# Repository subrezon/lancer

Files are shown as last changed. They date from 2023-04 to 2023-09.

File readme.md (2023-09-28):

# Lancer

The Lancer is a 36-key ortholinear keyboard with a light split and a focus on compact footprint and portability. It is a direct successor to [la_nc](https://github.com/subrezon/la_nc), and is very much inspired by other keyboards like Planck, Lumberjack and Lesovoz.





# Features

- Width of just 11U, the smallest possible with 10 columns and a top-mounted Pro Micro
- More focused thumb row, featuring 6 easily accessible keys
- Powered by a Pro Micro or any other compatible MCU board
- Hotswap sockets in south-facing orientation
- Integrated battery support with a power switch
- Native 3-wire SPI for nice!view support without any bodge wires
- Backwards compatible with oldschool SSD1306 OLEDs (4 leftmost pins of the SPI header)  

# BOM

| Item | Count | Notes |
| :- | :- | :- |
| PCB | 1x | [Gerber file](https://github.com/subrezon/lancer/raw/master/gerbers/lancer-pcb-hotswap/lancer-hotswap-pcb.zip) |
| Top plate | 1x | [Gerber for FR4](https://github.com/subrezon/lancer/raw/master/gerbers/lancer-top-plate/lancer-top-plate.zip), [dxf for other materials](https://github.com/subrezon/lancer/raw/master/dxf/top-plate.dxf) |
| Bottom plate | 1x | [Gerber for FR4](https://github.com/subrezon/lancer/raw/master/gerbers/lancer-bottom-plate/lancer-bottom-plate.zip), [dxf for other materials](https://github.com/subrezon/lancer/raw/master/dxf/bottom-plate.dxf) |
| Pro Micro | 1x | other boards with compatible pinout also work |
| SMD Diodes | 36x | 1N4148W SOD123 |
| MX Hotswap sockets | 36x | Kailh or Gateron |
| Tactile button | 1x | 3x6mm 2-pin button |
| M2 screws | 16x | M2x4 or M2x5, head diameter <5mm |
| M2 standoffs | 8x | 8mm recommended[^1] |
| MX-style switches| 36x | 3-pin or 5-pin |
| 1U MX keycaps | 36x |  |

For wireless operation:

| Item | Count | Notes |
| :- | :- | :- |
| Wireless Pro Micro | 1x | nice!nano, nrfmicro, etc. |
| Rechargeable battery | 1x | 3.7V two-wire battery (eg. 350926) |
| 7-pin SPDT switch | 1x | MSK-12C02 or compatible |

Optionally:

| Item | Count | Notes |
| :- | :- | :- |
| Pro Micro socket | 1-2x | either 1x 24-pin wide or 2x 12-pin single-row |
| Screen | 1x | either nice!view or SSD1306 128x32 OLED |
| Screen socket | 1x | 5-pin |
| Screen cover | 1x | dxf file (coming soon) |

[^1]: 8mm is recommended and will result in equal spacing between top plate, PCB and bottom plate. 7mm can be used for the lowest possible profile, however it is only compatible with Kailh sockets - Gateron sockets slightly thicker.

# Tools

Required:

- Soldering iron/station (+ solder, flux, etc.)
- Screwdriver for the screws
- Side cutters (regular wire cutters will do in a pinch)

Optional (but very recommended):

- Tweezers (preferably reverse ones, for placing diodes & sockets)
- Breadboard (for aligning ProMicro pins)
- Tape (for holding components in place)

Safety measures:

- Fan (for blowing solder fumes away from your face)
- Eye protection (for trimming pins)

# PCB & plates fabrication

Upload the [PCB gerber file](https://github.com/subrezon/lancer/raw/master/gerbers/lancer-pcb-hotswap/lancer-hotswap-pcb.zip) to a PCB manufacturer site like JLCPCB or PCBWay. You can keep settings at default and just pick the color.

If you want FR4 plates, upload [top plate](https://github.com/subrezon/lancer/raw/master/gerbers/lancer-top-plate/lancer-top-plate.zip) and [bottom plate](https://github.com/subrezon/lancer/raw/master/gerbers/lancer-bottom-plate/lancer-bottom-plate.zip) gerbers in the same fashion. If you want plastic or metal plates, use [top plate](https://github.com/subrezon/lancer/raw/master/dxf/top-plate.dxf) and [bottom plate](https://github.com/subrezon/lancer/raw/master/dxf/bottom-plate.dxf) dxf files for cutting.

# Build guide

[Here is a WIP build guide in english](https://github.com/subrezon/lancer/blob/master/docs/build-guide.md). Feel free to submit better photos or translations!

# Firmware

Lancer supports all 3 major firmwares: QMK, ZMK and KMK.

Lancer support in QMK and KMK has been merged into their respective official repositories.

ZMK is user config repository only. Merging into official ZMK repository is currently not planned.

## QMK

The keyboard ID is `subrezon/lancer` in QMK.

Here is an example of flashing the keyboard with the default firmware using the QMK CLI:

```
qmk flash -kb subrezon/lancer -km default
```

If you're unsure what to do with this information, check out the [QMK Documentation](https://docs.qmk.fm/#/) for information on how to get started with QMK.

- I currently do not offer VIA support.
- QMK currently does not support nice!view E-Ink screens.
- If you want to use an SSD1306 OLED, [read this](https://docs.qmk.fm/#/feature_oled_driver) to make it work. The default firmware does not feature any screen support.
- The default firmware is set up for oldschool atmega32u4-based Pro Micros with the caterina bootloader. If you're using an STM or RP2040-based board, you will need to set CONVERT_TO accordingly in your keymap's rules.mk file. [Read this](https://docs.qmk.fm/#/feature_converters?id=converters) for further information.

## ZMK

You can use [this ZMK user config repository](https://github.com/subrezon/zmk-config-lancer) to build ZMK firmware for Lancer. You can:

- Download pre-built firmware from that repository. It is configured for nice!nano v2 and uses the default keymap.
- If you wish to change the keymap and/or use an MCU board other than nice!nano v2, fork that repository and edit the files to suit your needs. The keymap is under `config/boards/shields/lancer/lancer.keymap`.
- If you already have a ZMK user config repository, you may integrate the contents of that repository into your own. Copy the `config/boards/shields/lancer` directory into your repository, then edit your build.yaml to include Lancer:

```
---
include:
  - board: your_other_board
    shield: your_other_shield
  - board: nice_nano_v2
    shield: lancer
```

If you are using an MCU board other than nice!nano v2, change the `nice_nano_v2` board identifier to whatever your board's identifier is. You can find supported boards and their respective identifiers [here](https://zmk.dev/docs/hardware#pro_micro).

If you're new to ZMK, check out the [ZMK documentation](https://zmk.dev/docs) on how to get started.

Note: I might get around to get Lancer officially supported in ZMK main repo, but I feel like Lancer would need to become at least moderately popular first to justify the work. A public user config repo will do for now.

## KMK

To install KMK firmware on your Lancer, follow these steps:

- Download the latest release of [CircuitPython](https://circuitpython.org/downloads) for your MCU board.
- Connect your MCU board to the computer and put it into flashing mode, usually by double-tapping RESET (non-RP2040), or holding BOOT and pressing RESET (RP2040)
- A USB storage device will appear. Copy the `adafruit-circuitpython-*.uf2` you just downloaded onto it and wait. The board will reboot and appear again as a USB storage device named `CIRCUITPY`.
- Download or clone the [KMK Firmware Repository](https://github.com/KMKfw/kmk_firmware). Copy the `kmk` folder and the `boot.py` file onto the MCU.
  - If you use a nice!nano or another MCU board with only 1MB of flash, you will need to [compile the firmware](http://kmkfw.io/docs/Officially_Supported_Microcontrollers#pre-compiling-kmk-for-nicenano) first.
- Delete the `code.py` file, and copy `main.py` and `kb.py` from the `boards/subrezon/lancer` folder.

The `kb.py` file has been set up for nice!nano v2. If you have another MCU board - open the `kb.py` folder and look at line 5. It says:

```
from kmk.quickpin.pro_micro.nice_nano import pinout as pins
```

Change `nice_nano` to match your MCU board. [These ones are supported](https://github.com/KMKfw/kmk_firmware/tree/master/kmk/quickpin/pro_micro).

If yours isn't in the list, you will have to edit the board's pinout yourself.

# Known issues

- The two southmost screws were placed below the middle of switches 4 and 7 of the third row. Unless you're using screws with very small screw heads, they need to be unscrewed before pulling out those two switches. Fixing this would be a plate layout change, so this will likely never be fixed to maintain compatibility between plate/PCB revisions.

# Changelog
- v1.1: first minor revision (latest version, not tested yet)
  - Screen socket moved 1.27mm to the south to make installing a battery underneath the MCU board easier. Hopefully 1.27mm is enough, otherwise it will be move even further away in the next revision.
  - North-facing footprints in thumb cluster, most people install their thumb keycaps upside down, so to maintain south-facingness switches had to be turned 180 degrees as well.
  - Added "ON" and "OFF" silkscreening on the PCB's top side to indicate how the power switch operates.
- v1.0: initial release version (tested, verified working)

# Coming soon

- Acrylic screen cover
- Soldered PCB option
- 3D-printable case options

# Special thanks

- ai03 - for the [MX_V2](https://github.com/ai03-2725/MX_V2) footprint library
- The fabulous mechanical keyboard community - for, well, everything!

# License

This hardware is licensed under the MIT License. You may use it in any way you want.

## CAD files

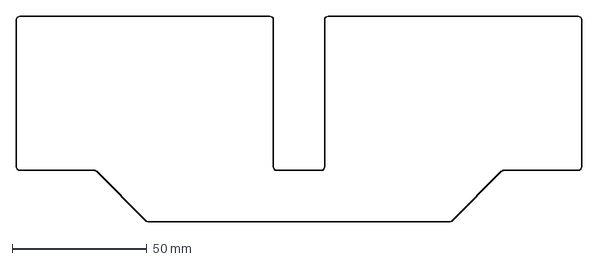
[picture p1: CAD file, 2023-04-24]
dxf/top-plate-outline.dxf
209.6 x 76.2 mm

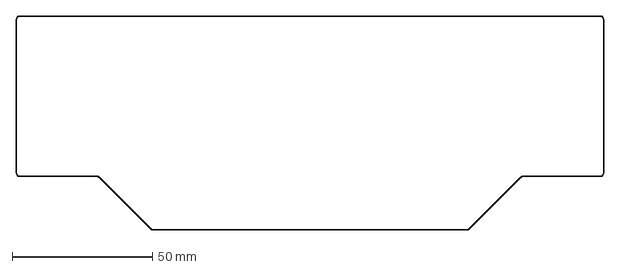
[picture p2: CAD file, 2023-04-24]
dxf/pcb-outline.dxf
209.6 x 76.2 mm

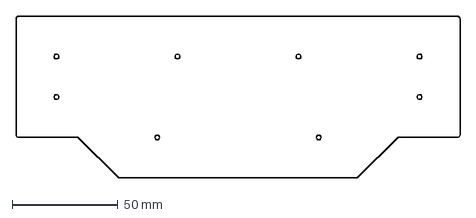
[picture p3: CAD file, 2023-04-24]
dxf/bottom-plate.dxf
209.6 x 76.2 mm

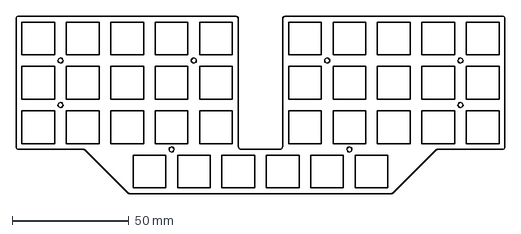
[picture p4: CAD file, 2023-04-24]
dxf/top-plate.dxf
209.6 x 76.2 mm

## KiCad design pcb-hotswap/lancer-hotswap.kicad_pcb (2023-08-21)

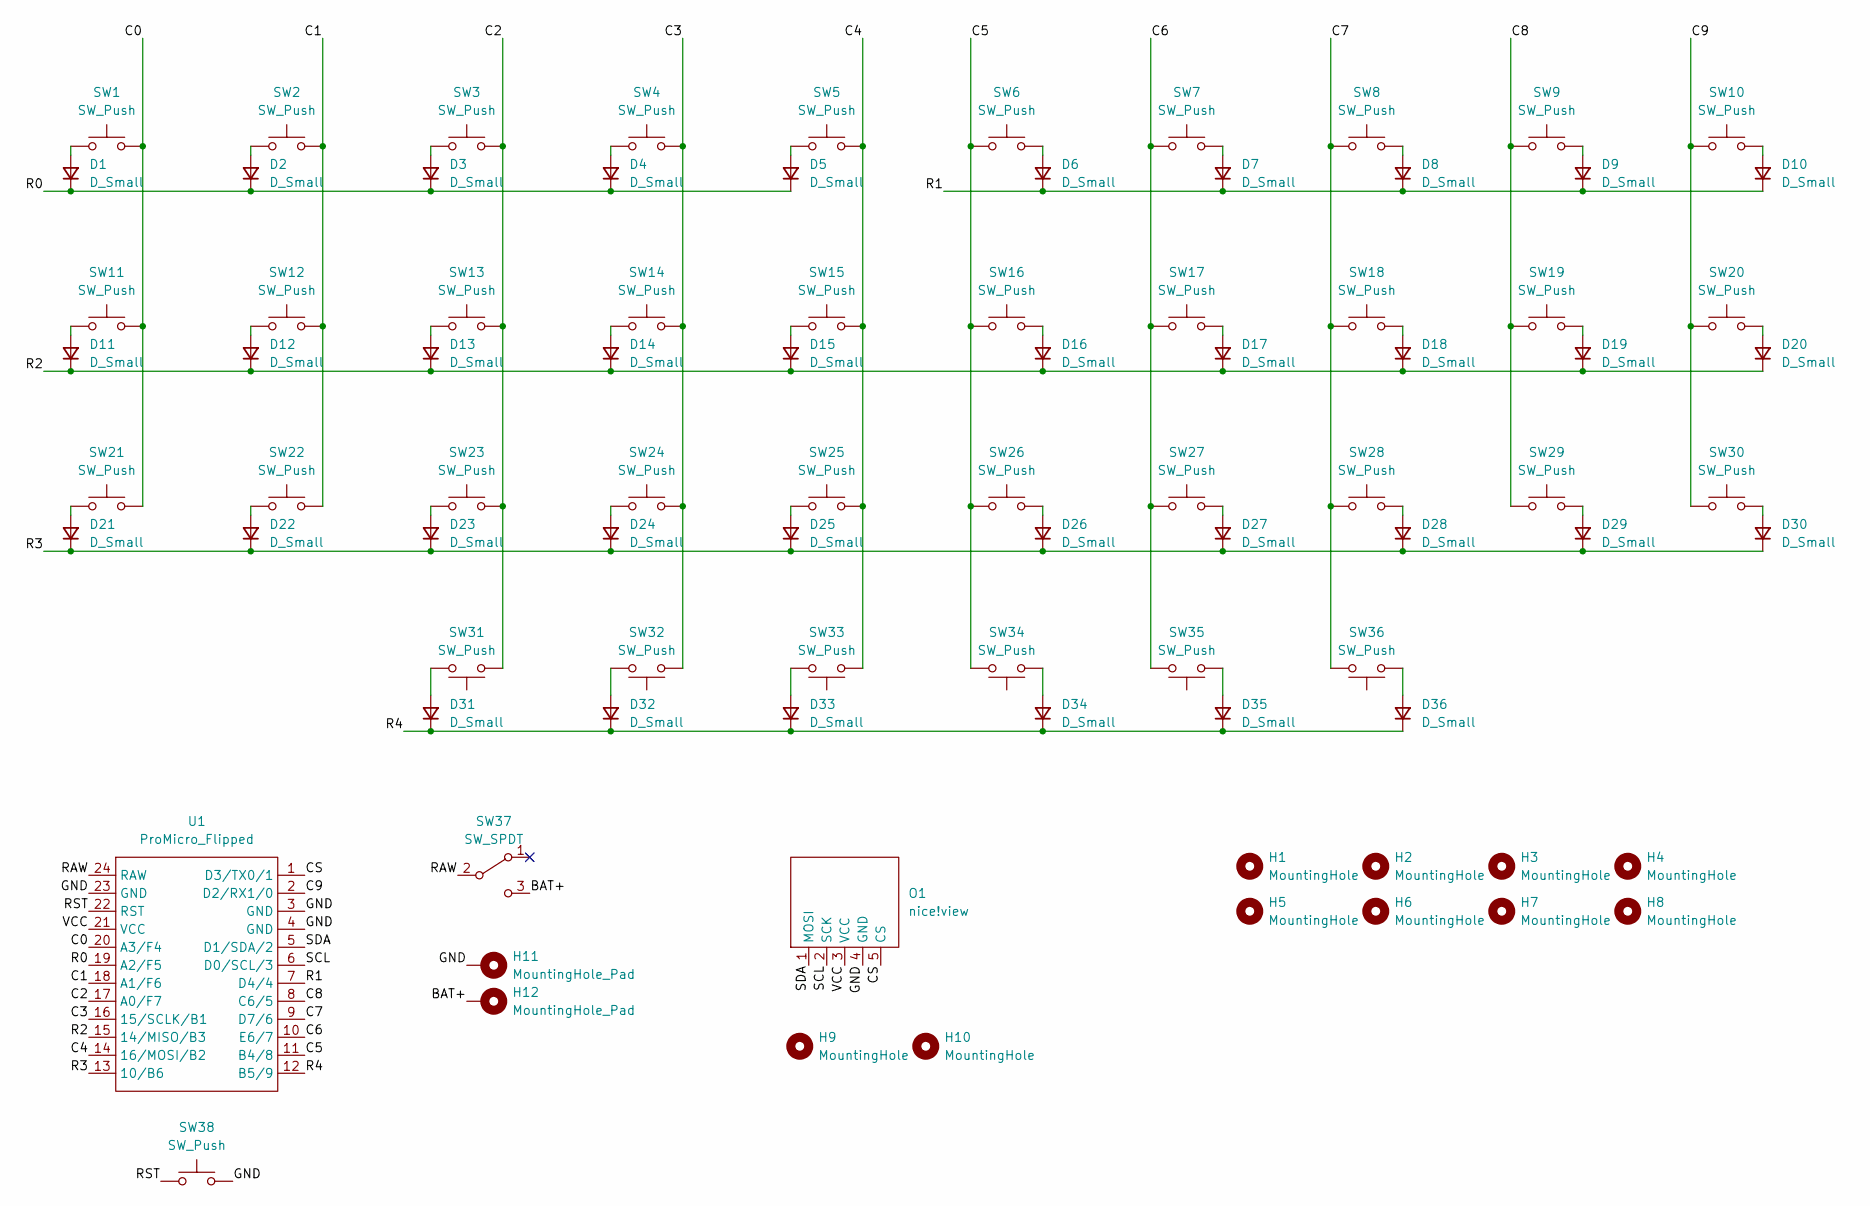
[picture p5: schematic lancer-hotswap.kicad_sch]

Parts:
D1, D2, D3, D4, D5, D6, D7, D8, D9, D10, D11, D12, D13, D14, D15, D16, D17, D18, D19, D20, D21, D22, D23, D24, D25, D26, D27, D28, D29, D30, D31, D32, D33, D34, D35, D36: D_Small; Diode_SMD
H1, H2, H3, H4, H5, H6, H7, H8: MountingHole; M2_StandoffHole
H9, H10: MountingHole; M2_ScrewHole
H11, H12: MountingHole_Pad; TH
O1: nice!view
SW1, SW2, SW3, SW4, SW5, SW6, SW7, SW8, SW9, SW10, SW11, SW12, SW13, SW14, SW15, SW16, SW17, SW18, SW19, SW20, SW21, SW22, SW23, SW24, SW25, SW26, SW27, SW28, SW29, SW30, SW31, SW32, SW33, SW34, SW35, SW36: SW_Push; MX-Hotswap-1U
SW37: SW_SPDT; SW_SPDT_PCM12
SW38: SW_Push; SW_Reset
U1: ProMicro_Flipped

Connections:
/BAT+: H12.1, SW37.3 (C)
/C0: SW1.2, SW11.2, SW21.2, U1.20 (A3/F4)
/C1: SW2.2, SW12.2, SW22.2, U1.18 (A1/F6)
/C2: SW3.2, SW13.2, SW23.2, SW31.1, U1.17 (A0/F7)
/C3: SW4.2, SW14.2, SW24.2, SW32.1, U1.16 (15/SCLK/B1)
/C4: SW5.2, SW15.2, SW25.2, SW33.1, U1.14 (16/MOSI/B2)
/C5: SW6.1, SW16.1, SW26.1, SW34.2, U1.11 (B4/8)
/C6: SW7.1, SW17.1, SW27.1, SW35.2, U1.10 (E6/7)
/C7: SW8.1, SW18.1, SW28.1, SW36.2, U1.9 (D7/6)
/C8: SW9.1, SW19.1, SW29.1, U1.8 (C6/5)
/C9: SW10.1, SW20.1, SW30.1, U1.2 (D2/RX1/0)
/CS: O1.5 (CS), U1.1 (D3/TX0/1)
/GND: H11.1, O1.4 (GND), SW38.2, U1.3 (GND), U1.4 (GND), U1.23 (GND)
/R0: D1.1 (K), D2.1 (K), D3.1 (K), D4.1 (K), D5.1 (K), U1.19 (A2/F5)
/R1: D6.1 (K), D7.1 (K), D8.1 (K), D9.1 (K), D10.1 (K), U1.7 (D4/4)
/R2: D11.1 (K), D12.1 (K), D13.1 (K), D14.1 (K), D15.1 (K), D16.1 (K), D17.1 (K), D18.1 (K), D19.1 (K), D20.1 (K), U1.15 (14/MISO/B3)
/R3: D21.1 (K), D22.1 (K), D23.1 (K), D24.1 (K), D25.1 (K), D26.1 (K), D27.1 (K), D28.1 (K), D29.1 (K), D30.1 (K), U1.13 (10/B6)
/R4: D31.1 (K), D32.1 (K), D33.1 (K), D34.1 (K), D35.1 (K), D36.1 (K), U1.12 (B5/9)
/RAW: SW37.2 (B), U1.24 (RAW)
/RST: SW38.1, U1.22 (RST)
/SCL: O1.2 (SCK), U1.6 (D0/SCL/3)
/SDA: O1.1 (MOSI), U1.5 (D1/SDA/2)
/VCC: O1.3 (VCC), U1.21 (VCC)
unnamed: D1.2 (A), SW1.1
unnamed: D2.2 (A), SW2.1
unnamed: D3.2 (A), SW3.1
unnamed: D4.2 (A), SW4.1
unnamed: D5.2 (A), SW5.1
unnamed: D6.2 (A), SW6.2
unnamed: D7.2 (A), SW7.2
unnamed: D8.2 (A), SW8.2
unnamed: D9.2 (A), SW9.2
unnamed: D10.2 (A), SW10.2
unnamed: D11.2 (A), SW11.1
unnamed: D12.2 (A), SW12.1
unnamed: D13.2 (A), SW13.1
unnamed: D14.2 (A), SW14.1
unnamed: D15.2 (A), SW15.1
unnamed: D16.2 (A), SW16.2
unnamed: D17.2 (A), SW17.2
unnamed: D18.2 (A), SW18.2
unnamed: D19.2 (A), SW19.2
unnamed: D20.2 (A), SW20.2
unnamed: D21.2 (A), SW21.1
unnamed: D22.2 (A), SW22.1
unnamed: D23.2 (A), SW23.1
unnamed: D24.2 (A), SW24.1
unnamed: D25.2 (A), SW25.1
unnamed: D26.2 (A), SW26.2
unnamed: D27.2 (A), SW27.2
unnamed: D28.2 (A), SW28.2
unnamed: D29.2 (A), SW29.2
unnamed: D30.2 (A), SW30.2
unnamed: D31.2 (A), SW31.2
unnamed: D32.2 (A), SW32.2
unnamed: D33.2 (A), SW33.2
unnamed: D34.2 (A), SW34.1
unnamed: D35.2 (A), SW35.1
unnamed: D36.2 (A), SW36.1

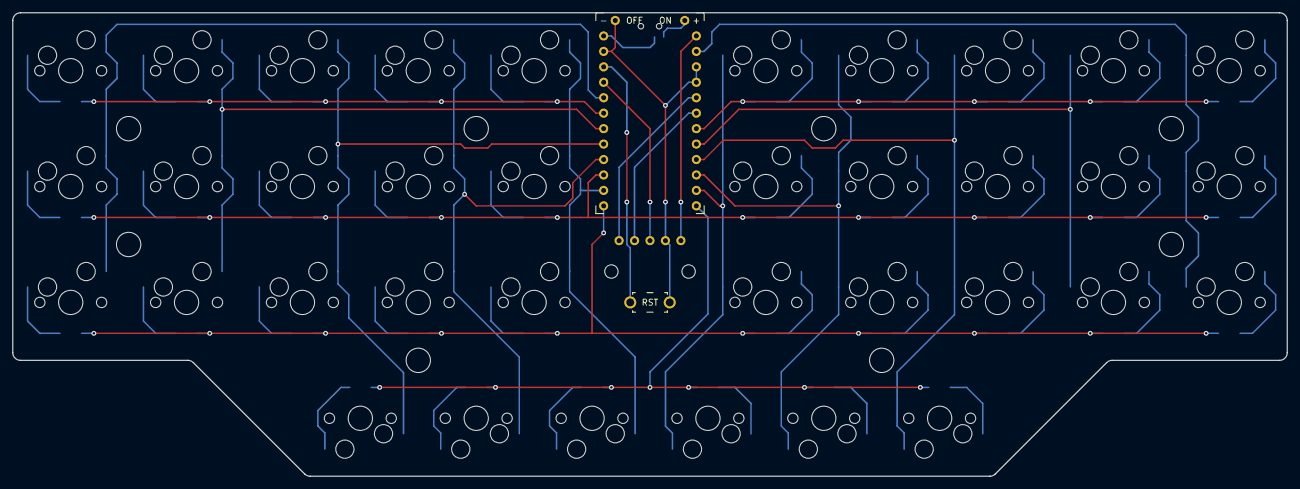
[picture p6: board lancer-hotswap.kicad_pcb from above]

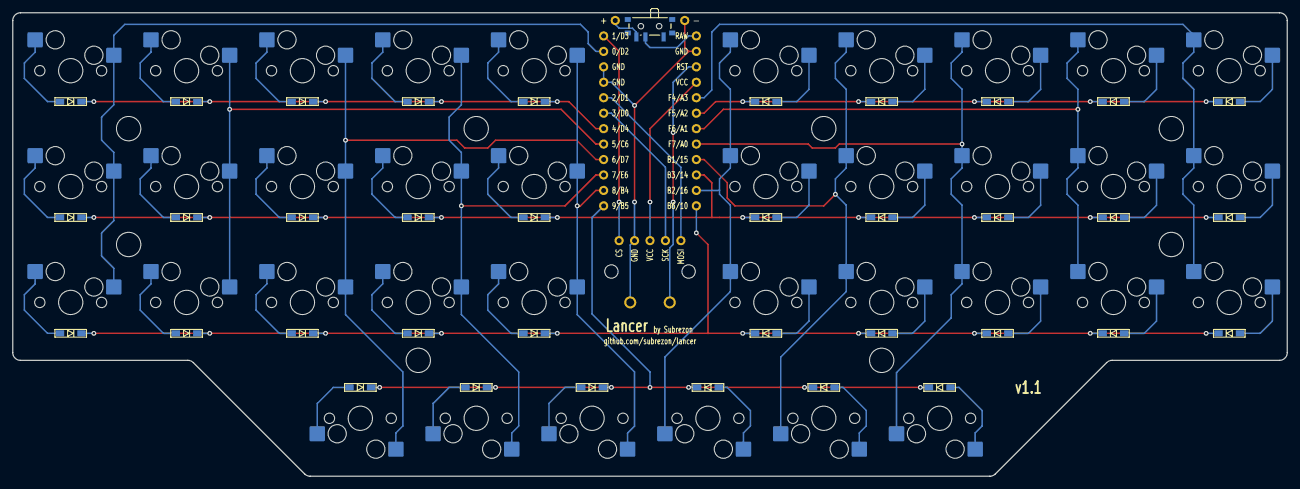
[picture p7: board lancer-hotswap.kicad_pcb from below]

Board: 2 copper layers, 209.5 x 76.2 mm, 88 parts (37 on the bottom side), 59 nets.

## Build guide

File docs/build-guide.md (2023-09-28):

# Build guide

This guide is very detailed and will describe the most efficient way of building the Lancer keyboard. As such, this guide assumes you're right-handed. If you hold the soldering iron with your left hand, mirror the steps for diode and socket soldering - do left pads first, then right pads.

Some photos are missing for now, I'll add them at a later point in time.

# Diodes

Start by placing your PCB face-down on your working surface. Heat up your soldering iron.

TODO PHOTO

Locate the diode footprints, this is what they look like:

TODO PHOTO

Put a dab of solder on the right pad of all 36 diode footprints. Then pick up a diode using tweezers with your left hand, reflow the solder with the soldering iron in your right hand, place the diode in the correct position, pull away the the iron and let the solder cool down again, while holding the diode still until it is fixed in place. Repeat 35 more times.

When soldering the first diode pin, focus on positioning the diode well. Because the solder is heated up twice and for a long time, the flux in it burns out, and the joint may look ugly for now, but that can be fixed later.

When placing the diodes, watch the orientation. The side with the line is called cathode. Place the diodes so that the arrow marking on the PCB points towards the cathode. All arrows point towards the center of the board, solder all diodes with their cathodes facing the center!

After soldering all 36 diodes by one pin, solder the others. Turn the board 180 degrees, now the unsoldered pads are all comfortably on the right. Solder the remaining 36 pins.

You can now go back to fix ugly joints from before by just putting some flux onto them and re-heating them briefly.

This is what the final result should look like:

TODO PHOTO

# Hotswap sockets

Locate the hotswap socket footprints, this is what they look like:

TODO PHOTO

Put a dab of solder on the right pad of all 36 socket footprint, it should look like a sofa pillow:

TODO PHOTO

Place a hotswap socket on the footprint, making sure that the socket pins match with the holes in the PCB. Heat the pad again, while pushing the right contact into the melted solder using tweezers. Make sure to push the metal part, not the plastic!

Once the socket is completely inserted, hold the soldering iron for a second or two to make sure the solder makes good contact, then let it cool and solidify. Repeat 35 more times.

After soldering all 36 sockets by one contact, solder the others. Turn the board 180 degrees, now the unsoldered contacts are all comfortably on the right. Solder the remaining 36 contacts, making sure to use enough solder and to hold the soldering iron for a bit to make sure the solder makes good contact. This is what the final result should look like:

TODO PHOTO

# Power switch

This step is only required for wireless boards, however I recommend you solder it now even if you don't currently plan to use wireless controllers. It's easier to do this without a Pro Micro installed, you'll save yourself a lot of hassle if you do ever decide to try out wireless.

Place the power switch on its footprint (top center of the board's back side). Make sure that the two plastic pegs go inside the holes in the PCB and that the pins line up with the pads.

Put a bit of solder on the tip of your iron, and while holding the switch in place using tweezers, tack any 2 pins in place. After that, solder the remaining pins. This is what the final result should look like:

TODO PHOTO

# Reset button

Put the reset button in from the top, flip the board and solder the pins. The result should look like this:

TODO PHOTO

# Pro Micro (without socket)

If you have a breadboard - stick the pin headers into it (with the longer pins side), place your Pro Micro onto the headers as flush as possible. You can optionally trim the pins so that they barely stick out (WHILE WEARING EYE PROTECTION!!!), or leave them as is. Now solder the pins to the Pro Micro. The final result should look like this:

TODO PHOTO

If you don't have a breadboard - you'll need to tape the headers to the Pro Micro somehow, or hold it in with one hand while soldering with another. Or just, like, get a breadboard, they're very useful and usually cost under $2.

# Prepare Pro Micro (with socket)

If you want to use a socket - stick the socket into the breadboard. Put tape over the socket to prevent solder from flowing into the socket when soldering the pins, like this:

TODO PHOTO

Stick the pins through the tape into the socket, then put the Pro Micro onto them. Trim the pins if they're too long (WHILE WEARING EYE PROTECTION!!!). It should look like this:

TODO PHOTO

Solder in the pins. Take the Pro Micro out of the socket and remove the tape from the socket and put the Pro Micro back into the socket.

TODO PHOTO

# Solder Pro Micro & battery

Take your Pro Micro assembly (either with headers directly soldered in or attached to a socket) and place it onto its footprint. If you're going wireless - also place the battery under it now. Make sure everything fits together, fix it in place with tape, turn the board around, then solder in all the pins.

TODO PHOTO

# OLED / nice!view / socket

Insert a screen, socketed or not, into the top of the PCB and tape it down firmly. Solder the pins, the result should look like this:

TODO PHOTO

# Final assembly

The PCB is done. Now let's assemble the board. Screw the 8x M2 standoffs into the top plate using M2 screws:

TODO PHOTO

Now insert 8 switches into these positions:

TODO PHOTO

Then, put the plate and switches into the PCB. After that, insert the rest of the switches:

TODO PHOTO

Flip the board around and put the bottom plate in place. Screw it into the standoffs and put rubber feet in these positions:

TODO PHOTO

Flip the board back around and put on the keycaps:

TODO PHOTO

# Flashing firmware

Consult the readme for the firmware you wish to install. If you're unsure which to use - go with QMK.

QMK is a very mature and reliable firmware, basically the industry standard. It is also your only option for AVR microcontrollers like the atmega32u4 found in most Pro Micros. It's a good start if you're new to custom keyboards. However, it has extremely limited wireless support.

ZMK is a more modern firmware based on Zephyr RTOS, with great wireless support. However, it requires a 32-bit microcontroller, so no AVR support. Use this if you have an ARM-based Pro Micro board (STM, RP2040, etc.)

KMK is the newest kid on the firmware block. While it requires powerful microcontrollers with CircuitPython support, it is very feature rich and extremely easy to reconfigure by just editing files in the keyboard's onboard storage, not requiring any tooling after initial installation. Use this if you want to reconfigure your board on the go without DFU or other dev tools.

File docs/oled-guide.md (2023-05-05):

# Enabling OLED support

Lancer supports a nice!view E-Ink screen, and through a happy little accident the leftmost 4 pins of the 5-pin SPI header match the pinout of an SSD1306 OLED screen. You can use those if you so desire, however I don't offer any support and you will have to set it up yourself. Here are a couple pointers on how to do that:

# Create a new keymap in QMK

Create a new keymap in QMK:

```
qmk new-keymap -kb subrezon/lancer -km my_oled_keymap
```

# rules.mk

Add the following lines at the end of `rules.mk` in your keymap folder (if the file isn't there - create it):

```
OLED_ENABLE = yes
OLED_DRIVER = SSD1306
```

# keymap.c

The default keymap is data-driven and not implemented in C code. As far as I know, this way of doing things isn't compatible with OLEDs.

First, delete the `keymap.json` file from your keymap. Then, create a `keymap.c` file. You will need to implement your keymap there, and then add your OLED code at the end. It should look something like this:

```
#include QMK_KEYBOARD_H

const uint16_t PROGMEM keymaps[][MATRIX_ROWS][MATRIX_COLS] = {

	// your keymap

};

#ifdef OLED_ENABLE

bool oled_task_user(void) {
	oled_write_P(PSTR("Layer:\n"), false);

    switch (get_highest_layer(layer_state)) {
    	case 0 :
            oled_write_P(PSTR("QWERTY\n"), false);
            break;

        case 1 :
            oled_write_P(PSTR("Numbers\n"), false);
            break;

        case 2 :
            oled_write_P(PSTR("Symbols\n"), false);
            break;

        case 3 :
            oled_write_P(PSTR("Options\n"), false);
            break;

        default :
        	oled_write_P(PSTR("Undefined\n"), false);
    }

    return false;
};

#endif
```

For further pointers, checkout out the QMK documentation, namely [this page](https://docs.qmk.fm/#/keymap) about C keymaps and [that page](https://docs.qmk.fm/#/feature_oled_driver) about configuring OLEDs.

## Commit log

2023-04-24 v1.0 went to production
    [bottom-plate.dxf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]
2023-05-05 oled stuff + switched to fancier code segments
2023-08-21 v1.1 gerbers
    [lancer-hotswap-B_Cu.gbr, lancer-hotswap-B_Mask.gbr, lancer-hotswap-B_Paste.gbr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]
